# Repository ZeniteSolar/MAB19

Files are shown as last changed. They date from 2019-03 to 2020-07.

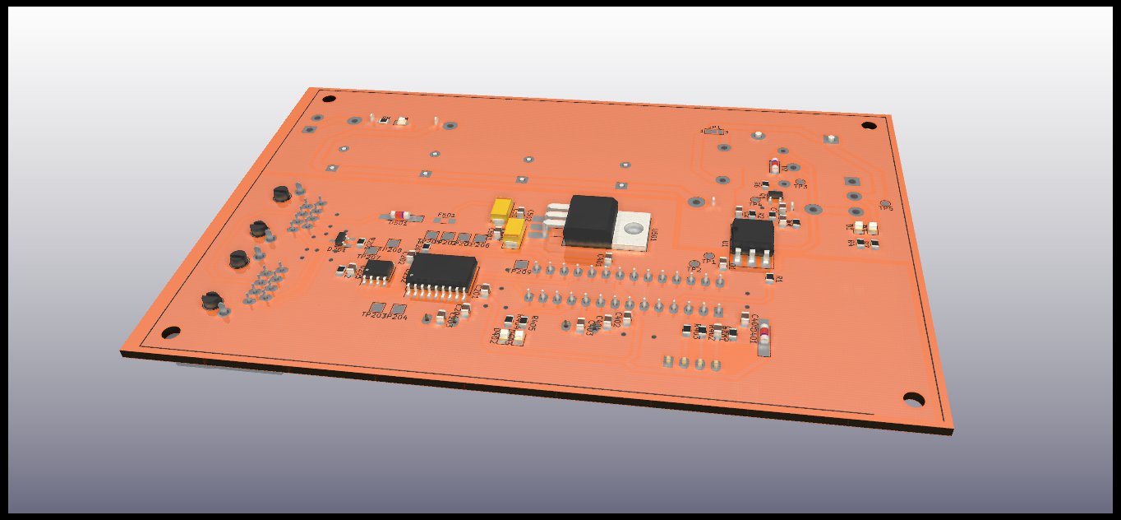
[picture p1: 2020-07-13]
hardware/IMG/3DDOWN.png

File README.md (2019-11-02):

# MAB19
Modulo de Acionamento das Bombas de porão

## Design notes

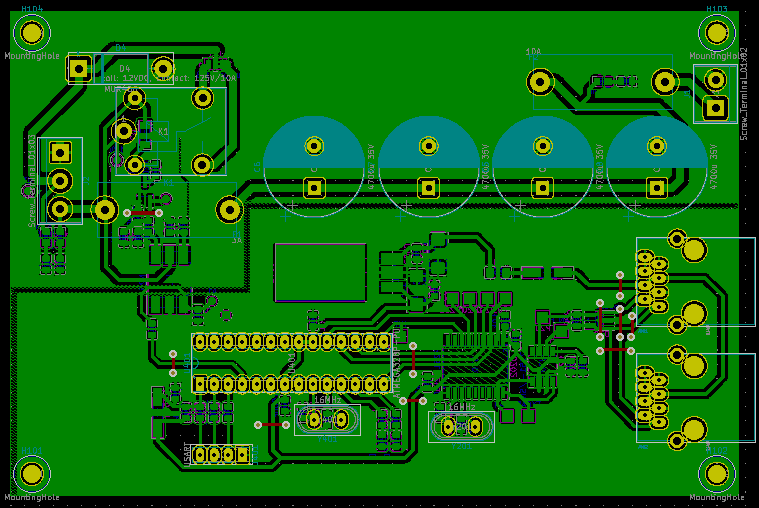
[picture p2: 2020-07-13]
hardware/IMG/layout.png

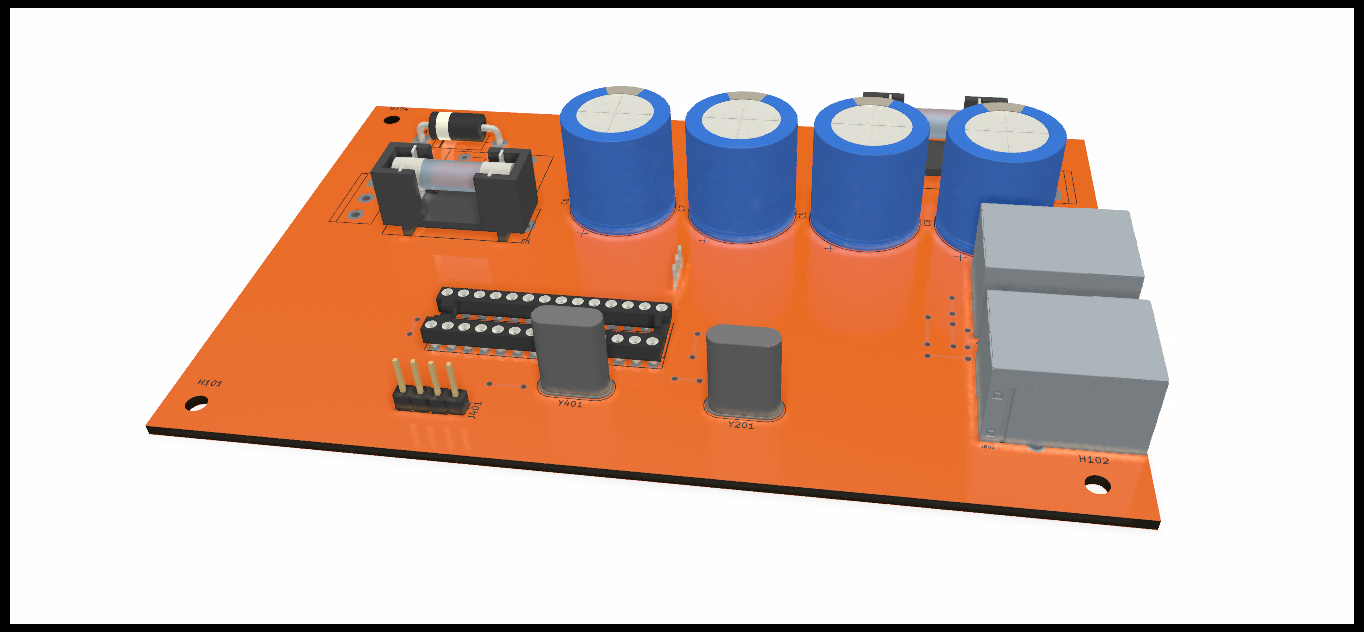
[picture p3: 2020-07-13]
hardware/IMG/3DUP.png

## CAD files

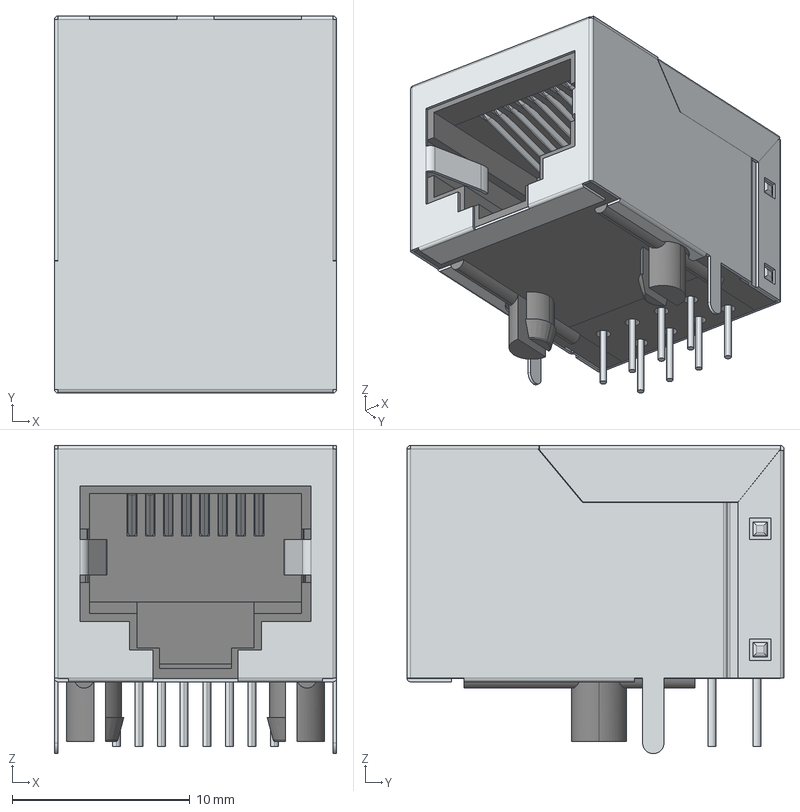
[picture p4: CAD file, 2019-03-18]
hardware/rj45.step
15.9 x 21.2 x 17.3 mm

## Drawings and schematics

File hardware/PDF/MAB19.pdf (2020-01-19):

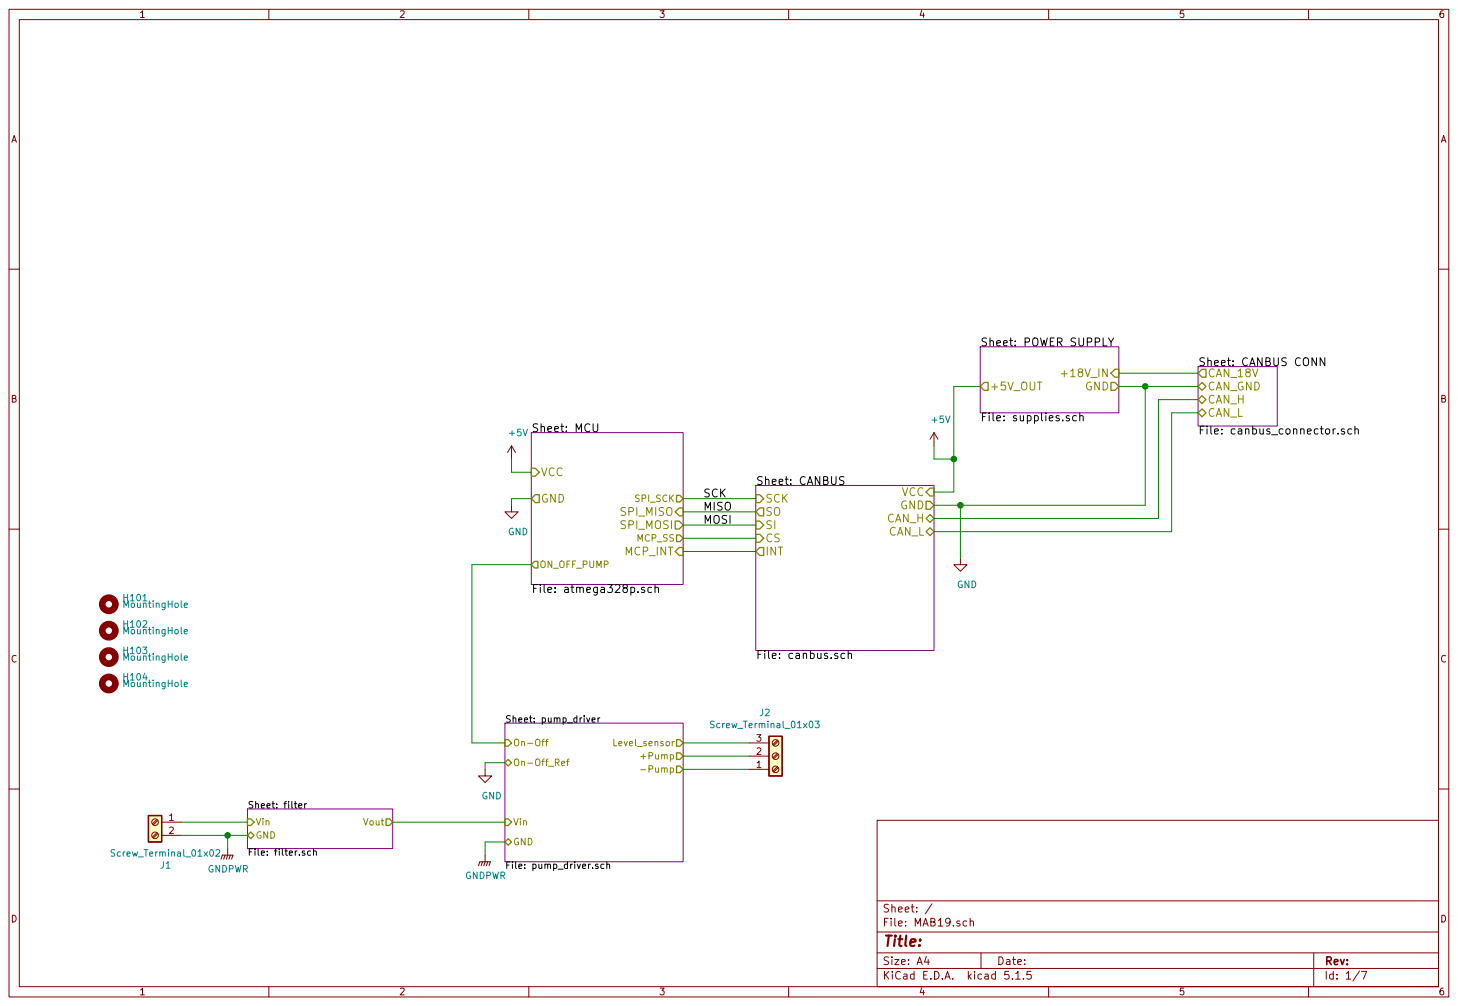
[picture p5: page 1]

Id: 1/7 Title: File: MAB19.sch Sheet: / Sheet: MCU
+5V GND GND

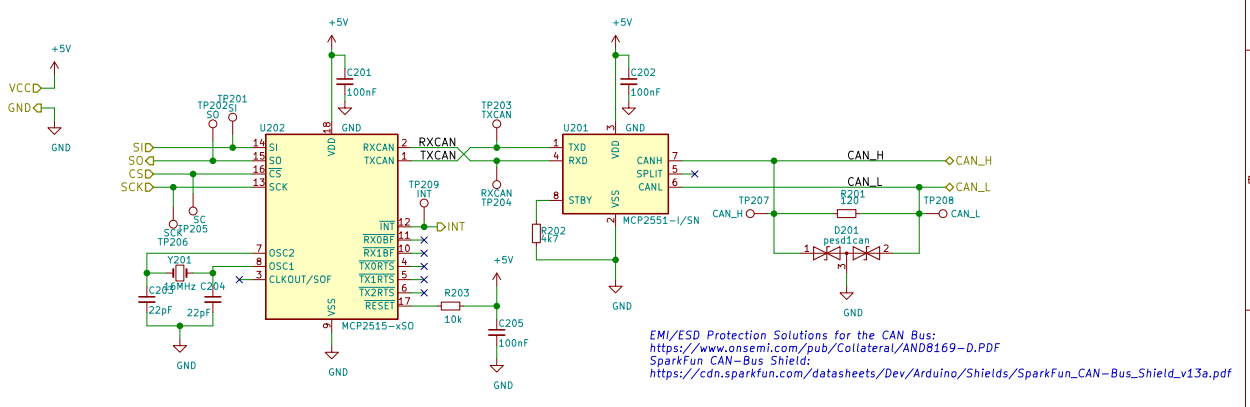
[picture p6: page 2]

3 RXD 4 SPLIT 5 CANL 6 CANH 7 STBY 8 U201 MCP2551-I/SN

EMI/ESD Protection Solutions for the CAN Bus:
https://www.onsemi.com/pub/Collateral/AND8169-D.PDF
SparkFun CAN-Bus Shield:
https://cdn.sparkfun.com/datasheets/Dev/Arduino/Shields/SparkFun_CAN-Bus_Shield_v13a.pdf

Id: 2/7 Title: File: canbus.sch Sheet: /CANBUS/

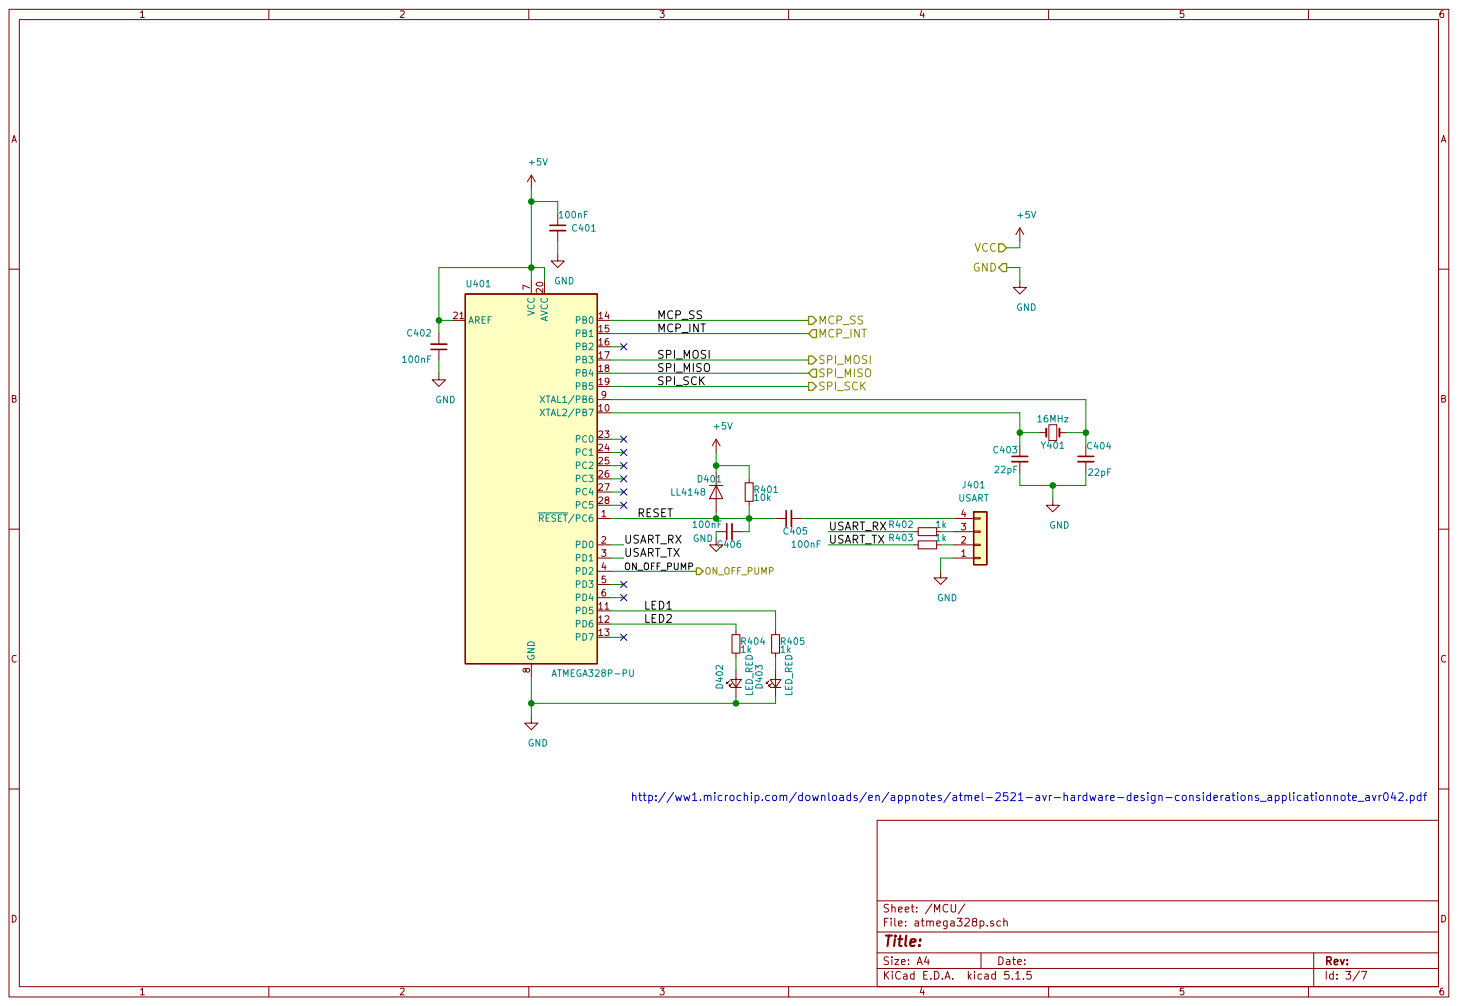
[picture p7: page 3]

http://ww1.microchip.com/downloads/en/appnotes/atmel-2521-avr-hardware-design-considerations_applicationnote_avr042.pdf

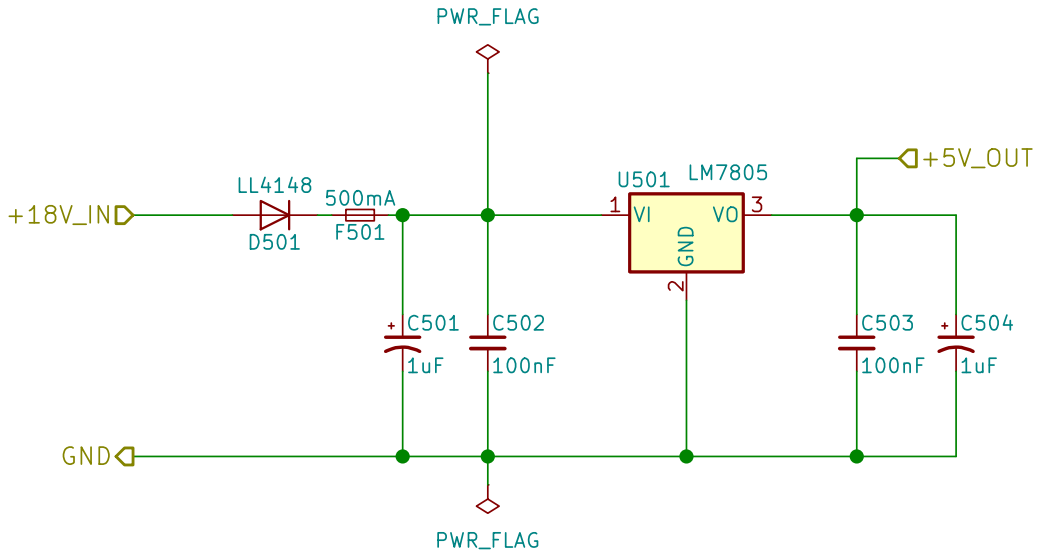
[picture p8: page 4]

File: supplies.sch Sheet: /POWER SUPPLY/
Id: 4/7 Title:

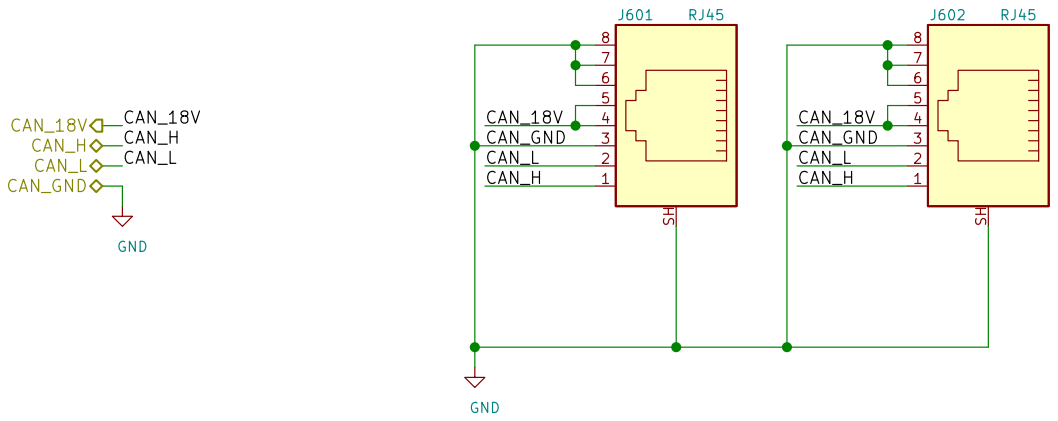
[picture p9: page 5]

File: canbus_connector.sch Sheet: /CANBUS CONN/ GND

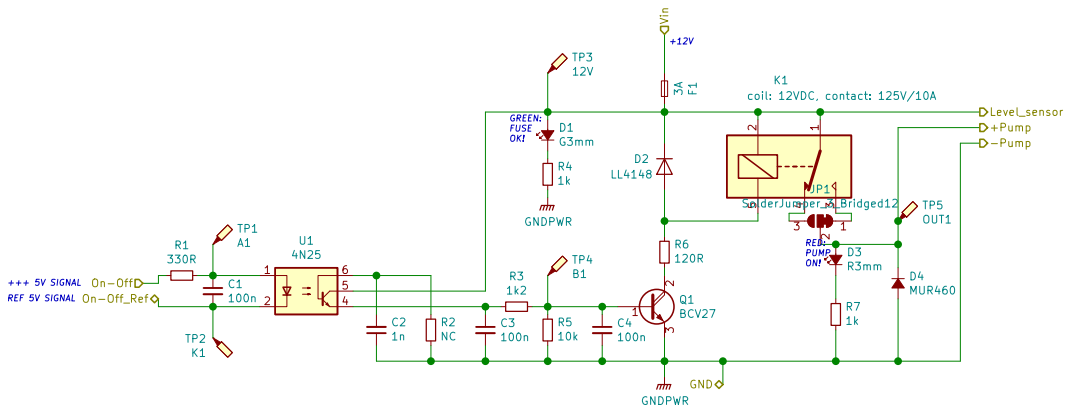
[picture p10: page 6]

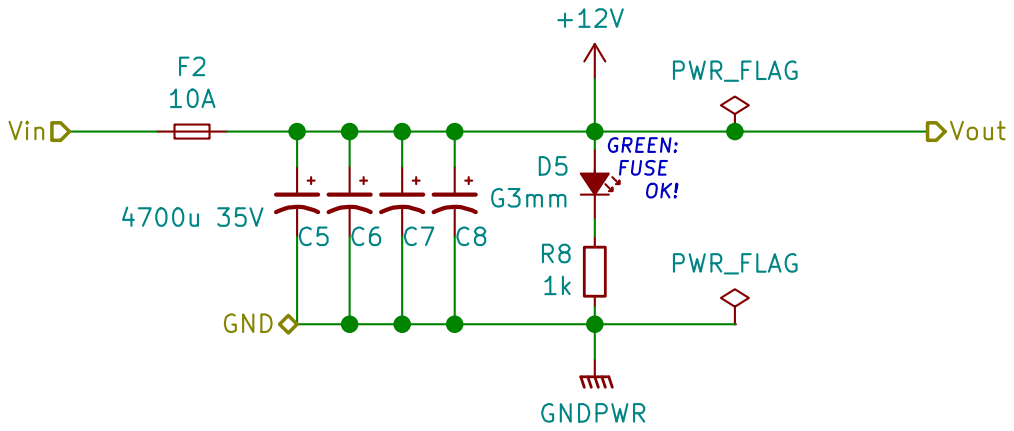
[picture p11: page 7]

Id: 7/7 Title: File: filter.sch Sheet: /filter/

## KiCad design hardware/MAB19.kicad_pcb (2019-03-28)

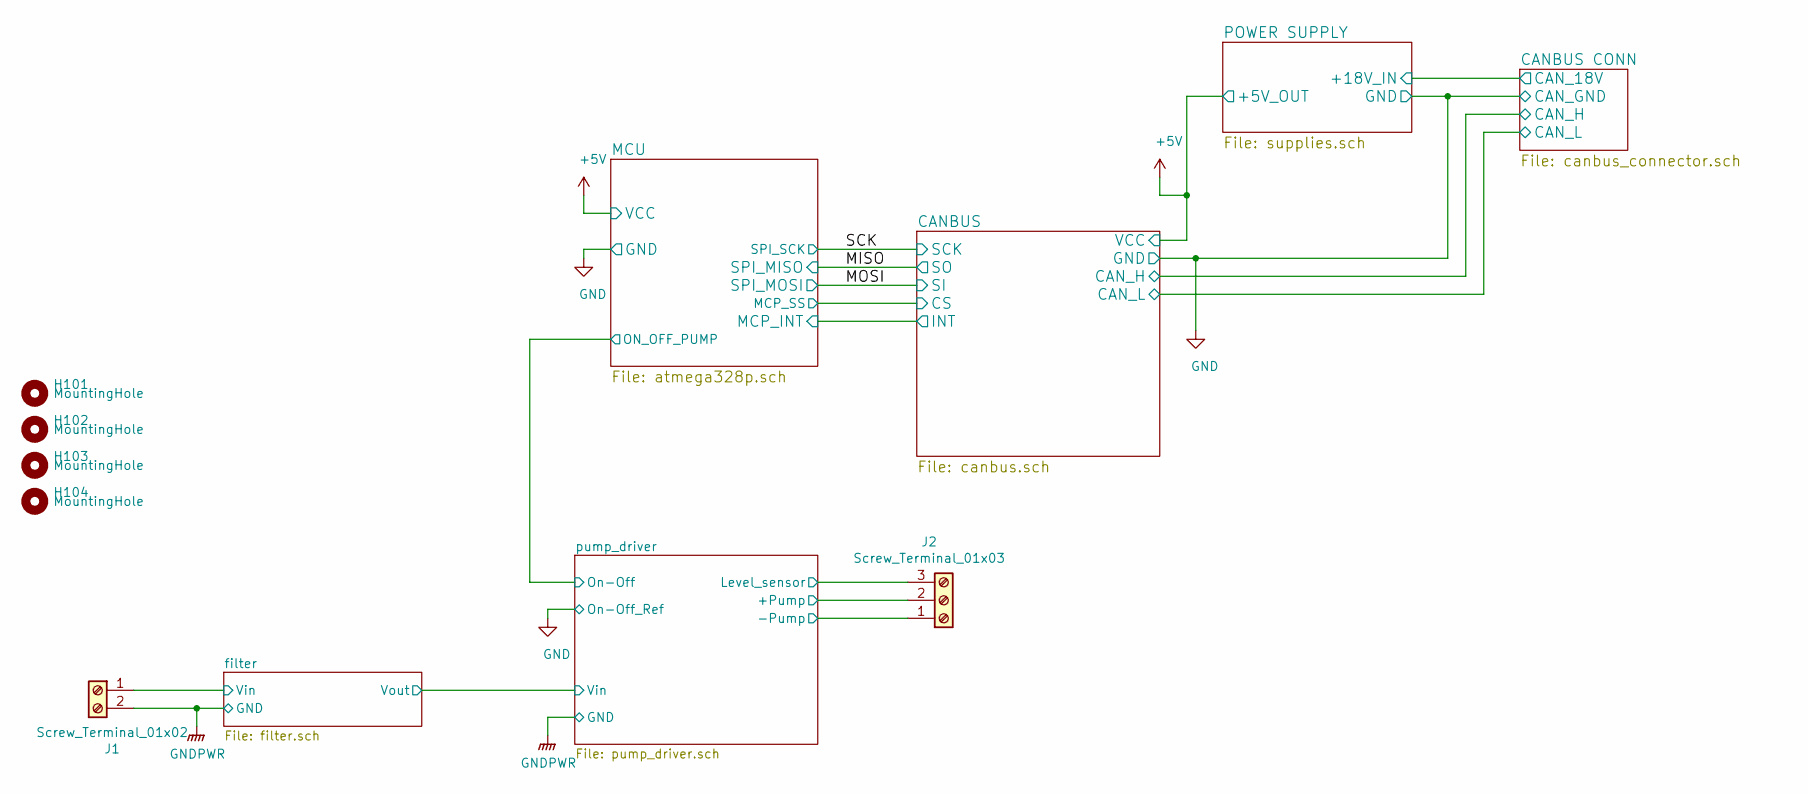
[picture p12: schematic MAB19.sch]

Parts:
H101, H102, H103, H104: MountingHole; MountingHole_3.2mm_M3
J1: Screw_Terminal_01x02; TerminalBlock_bornier-2_P5.08mm
J2: Screw_Terminal_01x03; TerminalBlock_bornier-3_P5.08mm

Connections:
/filter/Vin: J1.1; also elsewhere on the board
/pump_driver/+Pump: J2.2; also elsewhere on the board
GNDPWR: J1.2, J2.1; also elsewhere on the board

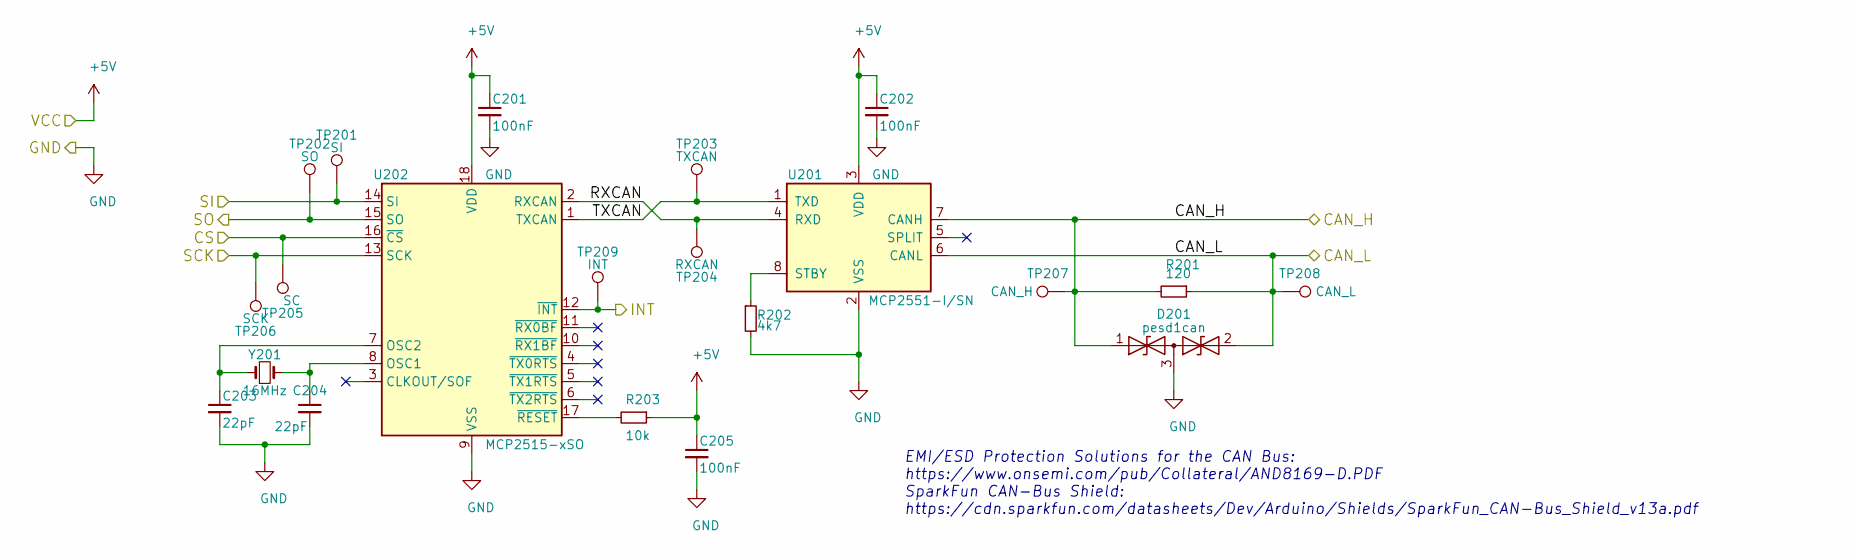
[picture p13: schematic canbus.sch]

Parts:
C201, C202, C205: 100nF; C_0805_2012Metric_Pad1.15x1.40mm_HandSolder
C203, C204: 22pF; C_0805_2012Metric_Pad1.15x1.40mm_HandSolder
D201: pesd1can; SOT-23_Handsoldering
R201: 120; R_0805_2012Metric_Pad1.15x1.40mm_HandSolder
R202: 4k7; R_0805_2012Metric_Pad1.15x1.40mm_HandSolder
R203: 10k; R_0805_2012Metric_Pad1.15x1.40mm_HandSolder
TP201: SI; TestPoint_Pad_2.0x2.0mm
TP202: SO; TestPoint_Pad_2.0x2.0mm
TP203: TXCAN; TestPoint_Pad_2.0x2.0mm
TP204: RXCAN; TestPoint_Pad_2.0x2.0mm
TP205: SC; TestPoint_Pad_2.0x2.0mm
TP206: SCK; TestPoint_Pad_2.0x2.0mm
TP207: CAN_H; TestPoint_Pad_2.0x2.0mm
TP208: CAN_L; TestPoint_Pad_2.0x2.0mm
TP209: INT; TestPoint_Pad_2.0x2.0mm
U201: MCP2551-I/SN; SOIC-8_3.9x4.9mm_P1.27mm
U202: MCP2515-xSO; SOIC-18W_7.5x11.6mm_P1.27mm
Y201: 16MHz; Crystal_HC49-U_Vertical

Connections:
+5V: C201.1, C202.1, C205.1, R203.1, U201.3 (VDD), U202.18 (VDD); also elsewhere on the board
/CANBUS CONN/CAN_H: D201.1 (A1), R201.2, TP207.1, U201.7 (CANH); also elsewhere on the board
/CANBUS CONN/CAN_L: D201.2 (A2), R201.1, TP208.1, U201.6 (CANL); also elsewhere on the board
/CANBUS/CS: TP205.1, U202.16 (~CS); also elsewhere on the board
/CANBUS/INT: TP209.1, U202.12 (~INT); also elsewhere on the board
/CANBUS/RXCAN: TP204.1, U201.4 (RXD), U202.2 (RXCAN)
/CANBUS/TXCAN: TP203.1, U201.1 (TXD), U202.1 (TXCAN)
/MISO: TP202.1, U202.15 (SO); also elsewhere on the board
/MOSI: TP201.1, U202.14 (SI); also elsewhere on the board
/SCK: TP206.1, U202.13 (SCK); also elsewhere on the board
GND: C201.2, C202.2, C203.2, C204.2, C205.2, D201.3 (common), R202.2, U201.2 (VSS), U202.9 (VSS); also elsewhere on the board
unnamed: C203.1, U202.7 (OSC2), Y201.1
unnamed: C204.1, U202.8 (OSC1), Y201.2
unnamed: R202.1, U201.8 (STBY)
unnamed: R203.2, U202.17 (~RESET)

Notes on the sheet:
EMI/ESD Protection Solutions for the CAN Bus: https://www.onsemi.com/pub/Collateral/AND8169-D.PDF SparkFun CAN-Bus Shield: https://cdn.sparkfun.com/datasheets/Dev/Arduino/Shields/SparkFun_CAN-Bus_Shield_v13a.pdf

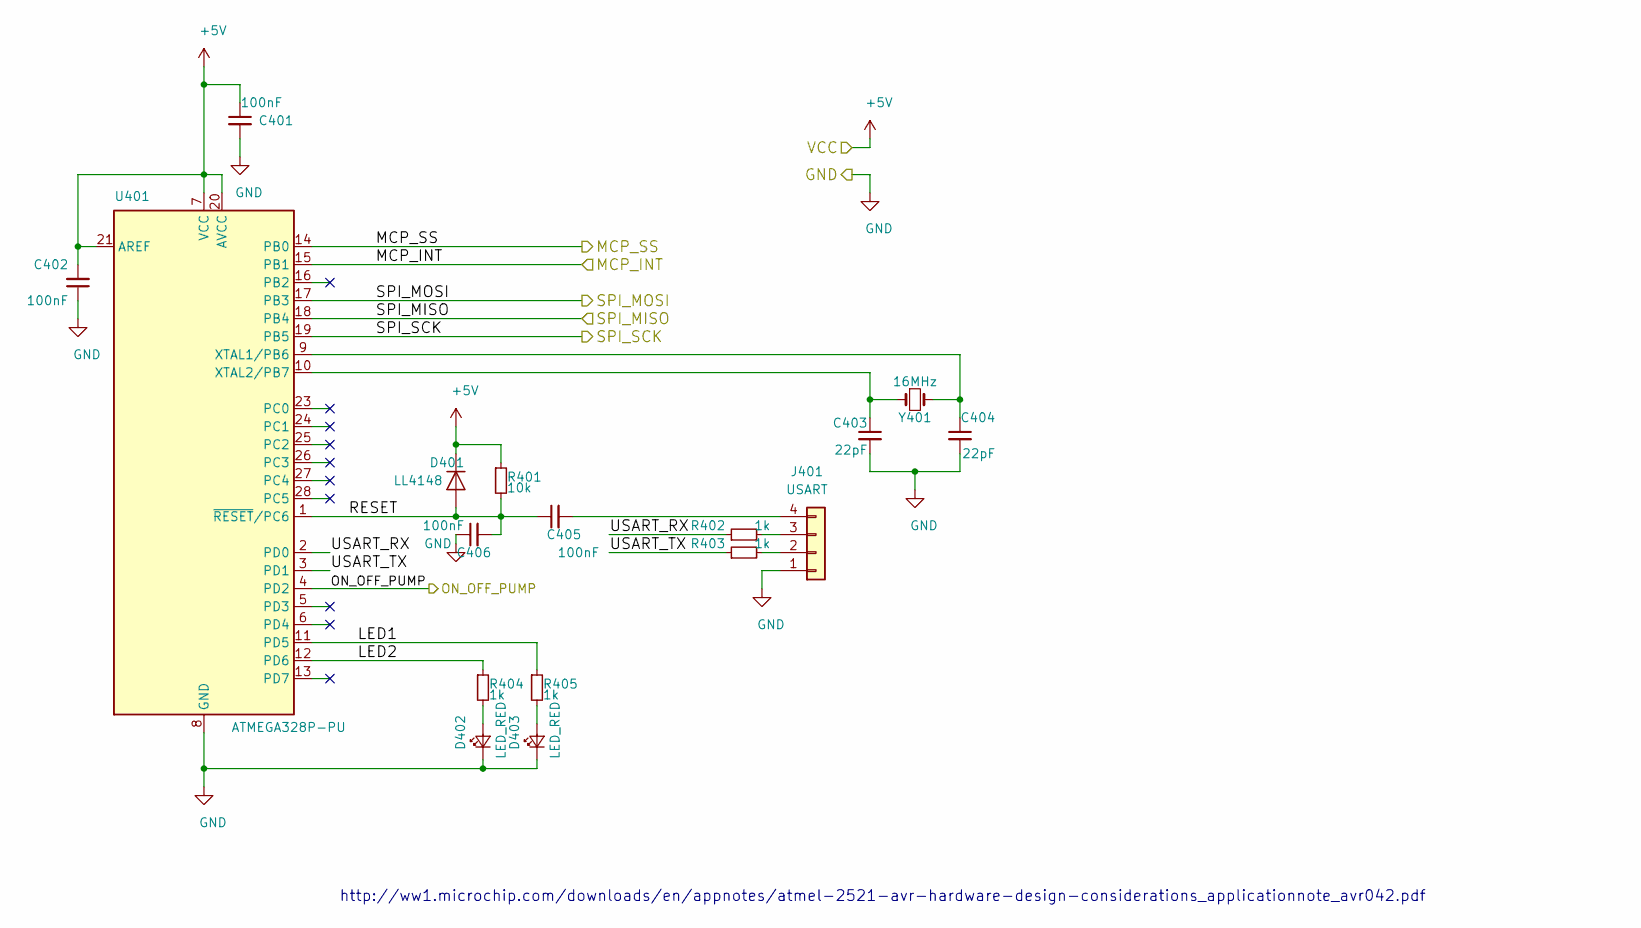
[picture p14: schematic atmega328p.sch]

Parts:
C401, C402, C405, C406: 100nF; C_0805_2012Metric_Pad1.15x1.40mm_HandSolder
C403, C404: 22pF; C_0805_2012Metric_Pad1.15x1.40mm_HandSolder
D401: LL4148; D_MiniMELF_Handsoldering
D402, D403: LED_RED; LED_0805_2012Metric_Pad1.15x1.40mm_HandSolder
J401: USART; PinHeader_1x04_P2.54mm_Vertical
R401: 10k; R_0805_2012Metric_Pad1.15x1.40mm_HandSolder
R402, R403, R404, R405: 1k; R_0805_2012Metric_Pad1.15x1.40mm_HandSolder
U401: ATMEGA328P-PU; DIP-28_W7.62mm_Socket
Y401: 16MHz; Crystal_HC49-U_Vertical

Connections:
+5V: C401.1, C402.2, D401.1 (K), R401.1, U401.7 (VCC), U401.20 (AVCC), U401.21 (AREF); also elsewhere on the board
/CANBUS/CS: U401.14 (PB0); also elsewhere on the board
/CANBUS/INT: U401.15 (PB1); also elsewhere on the board
/MCU/LED1: R405.1, U401.11 (PD5)
/MCU/LED2: R404.1, U401.12 (PD6)
/MCU/ON_OFF_PUMP: U401.4 (PD2); also elsewhere on the board
/MCU/RESET: C405.1, C406.2, D401.2 (A), R401.2, U401.1 (~RESET~/PC6)
/MCU/USART_RX: R402.1, U401.2 (PD0)
/MCU/USART_TX: R403.1, U401.3 (PD1)
/MISO: U401.18 (PB4); also elsewhere on the board
/MOSI: U401.17 (PB3); also elsewhere on the board
/SCK: U401.19 (PB5); also elsewhere on the board
GND: C401.2, C402.1, C403.2, C404.2, C406.1, D402.1 (K), D403.1 (K), J401.1, U401.8 (GND), U401.22 (GND); also elsewhere on the board
unnamed: C403.1, U401.10 (XTAL2/PB7), Y401.1
unnamed: C404.1, U401.9 (XTAL1/PB6), Y401.2
unnamed: C405.2, J401.4
unnamed: D402.2 (A), R404.2
unnamed: D403.2 (A), R405.2
unnamed: J401.2, R403.2
unnamed: J401.3, R402.2

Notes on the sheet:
http://ww1.microchip.com/downloads/en/appnotes/atmel-2521-avr-hardware-design-considerations_applicationnote_avr042.pdf

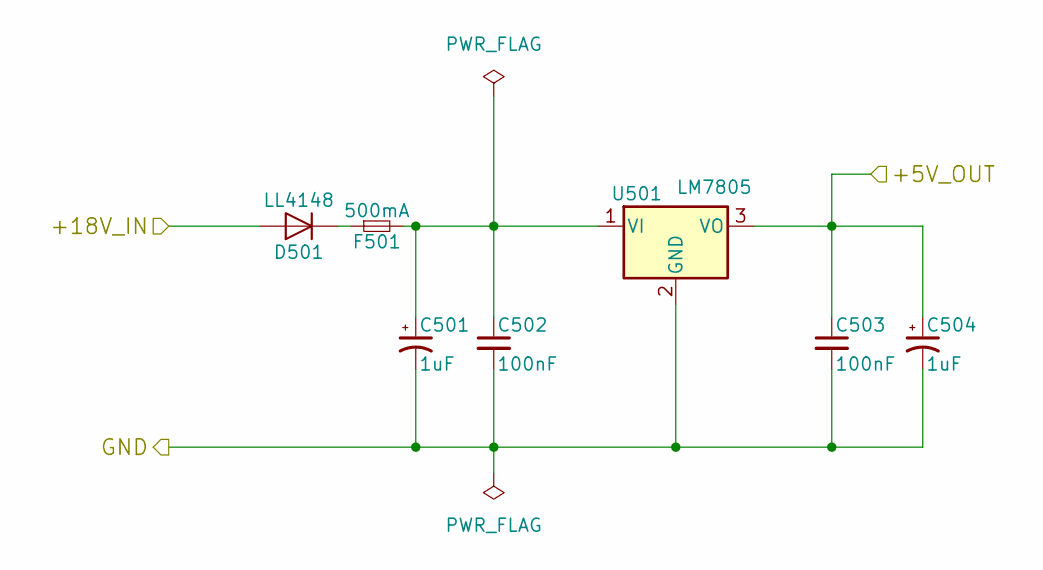
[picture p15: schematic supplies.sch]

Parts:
C501, C504: 1uF; CP_EIA-6032-20_AVX-F_Pad2.25x2.35mm_HandSolder
C502, C503: 100nF; C_0805_2012Metric_Pad1.15x1.40mm_HandSolder
D501: LL4148; D_MiniMELF_Handsoldering
F501: 500mA; Fuse_1206_3216Metric_Pad1.42x1.75mm_HandSolder
U501: LM7805; TO-220-3_Horizontal_TabDown_SMD

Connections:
+5V: C503.1, C504.1, U501.3 (VO); also elsewhere on the board
/POWER SUPPLY/+18V_IN: D501.2 (A); also elsewhere on the board
GND: C501.2, C502.2, C503.2, C504.2, U501.2 (GND); also elsewhere on the board
unnamed: C501.1, C502.1, F501.2, U501.1 (VI)
unnamed: D501.1 (K), F501.1

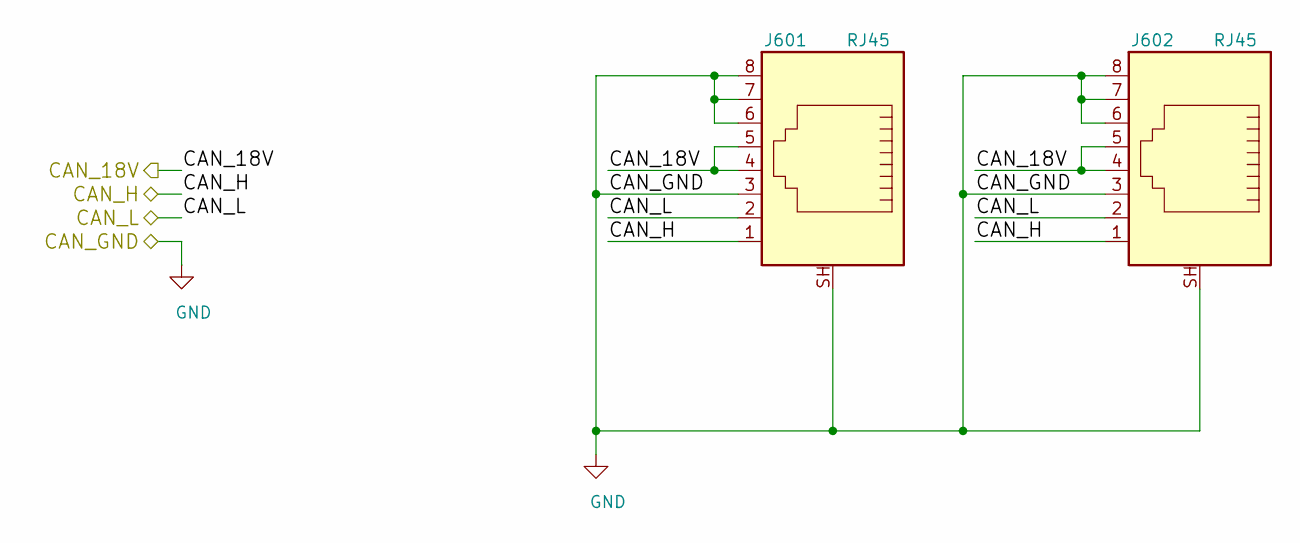
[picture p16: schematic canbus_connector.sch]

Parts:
J601, J602: RJ45; RJ45_YH59_01

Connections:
/CANBUS CONN/CAN_H: J601.1, J602.1; also elsewhere on the board
/CANBUS CONN/CAN_L: J601.2, J602.2; also elsewhere on the board
/POWER SUPPLY/+18V_IN: J601.4, J601.5, J602.4, J602.5; also elsewhere on the board
GND: J601.3, J601.6, J601.7, J601.8, J601.SH, J602.3, J602.6, J602.7, J602.8, J602.SH; also elsewhere on the board

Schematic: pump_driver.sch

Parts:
C1, C3, C4: 100n; C_0805_2012Metric_Pad1.15x1.40mm_HandSolder
C2: 1n; C_0805_2012Metric_Pad1.15x1.40mm_HandSolder
D1: G3mm; LED_0805_2012Metric_Pad1.15x1.40mm_HandSolder
D2: LL4148; D_MiniMELF
D3: R3mm; LED_0805_2012Metric_Pad1.15x1.40mm_HandSolder
D4: MUR460; D_DO-201AD_P15.24mm_Horizontal
F1: 3A; Fuse_Holder_5x20
JP1: SolderJumper_3_Bridged12; SolderJumper-3_P1.3mm_Bridged2Bar12_Pad1.0x1.5mm_NumberLabe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
K1: coil: 12VDC, contact: 125V/10A; Relay_SPDT_SANYOU_SRD_Series_Form_C
Q1: BCV27; TSOT-23_HandSoldering
R1: 330R; R_0805_2012Metric_Pad1.15x1.40mm_HandSolder
R2: NC; R_0805_2012Metric_Pad1.15x1.40mm_HandSolder
R3: 1k2; R_0805_2012Metric_Pad1.15x1.40mm_HandSolder
R4, R7: 1k; R_0805_2012Metric_Pad1.15x1.40mm_HandSolder
R5: 10k; R_0805_2012Metric_Pad1.15x1.40mm_HandSolder
R6: 120R; R_0805_2012Metric_Pad1.15x1.40mm_HandSolder
TP1: A1; TestPoint_Pad_D1.5mm
TP2: K1; TestPoint_Pad_D1.5mm
TP3: 12V; TestPoint_Pad_D1.5mm
TP4: B1; TestPoint_Pad_D1.5mm
TP5: OUT1; TestPoint_Pad_D1.5mm
U1: 4N25; DIP-6_W8.89mm_SMDSocket_LongPads

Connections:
+12V: F1.1; also elsewhere on the board
/MCU/ON_OFF_PUMP: R1.2; also elsewhere on the board
/pump_driver/+Pump: D3.2 (A), D4.1 (K), JP1.2 (C), TP5.1; also elsewhere on the board
GND: C1.2, TP2.1, U1.2; also elsewhere on the board
GNDPWR: C2.1, C3.2, C4.2, D4.2 (A), Q1.2, R2.1, R4.1, R5.1, R7.1; also elsewhere on the board
unnamed: C1.1, R1.1, TP1.1, U1.1
unnamed: C2.2, R2.2, U1.6
unnamed: C3.1, R3.2, U1.4
unnamed: C4.1, Q1.1, R3.1, R5.2, TP4.1
unnamed: D1.1 (K), R4.2
unnamed: D3.1 (K), R7.2
unnamed: JP1.1 (A), K1.3
unnamed: JP1.3 (B), K1.4
unnamed: Q1.3, R6.1

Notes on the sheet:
RED: PUMP ON!
GREEN: FUSE OK!
+++ 5V SIGNAL
REF 5V SIGNAL
+12V

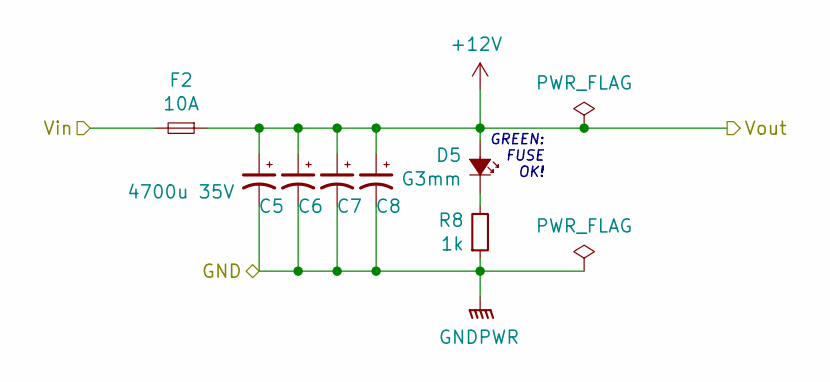
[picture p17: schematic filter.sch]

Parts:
C20, C21, C22, C23: 4700u 35V; CP_Radial_D18.0mm_P7.50mm
D10: G3mm; LED_0805_2012Metric_Pad1.15x1.40mm_HandSolder
F3: 10A; Fuse_Holder_5x20
R16: 1k; R_0805_2012Metric_Pad1.15x1.40mm_HandSolder

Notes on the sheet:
GREEN: FUSE OK!

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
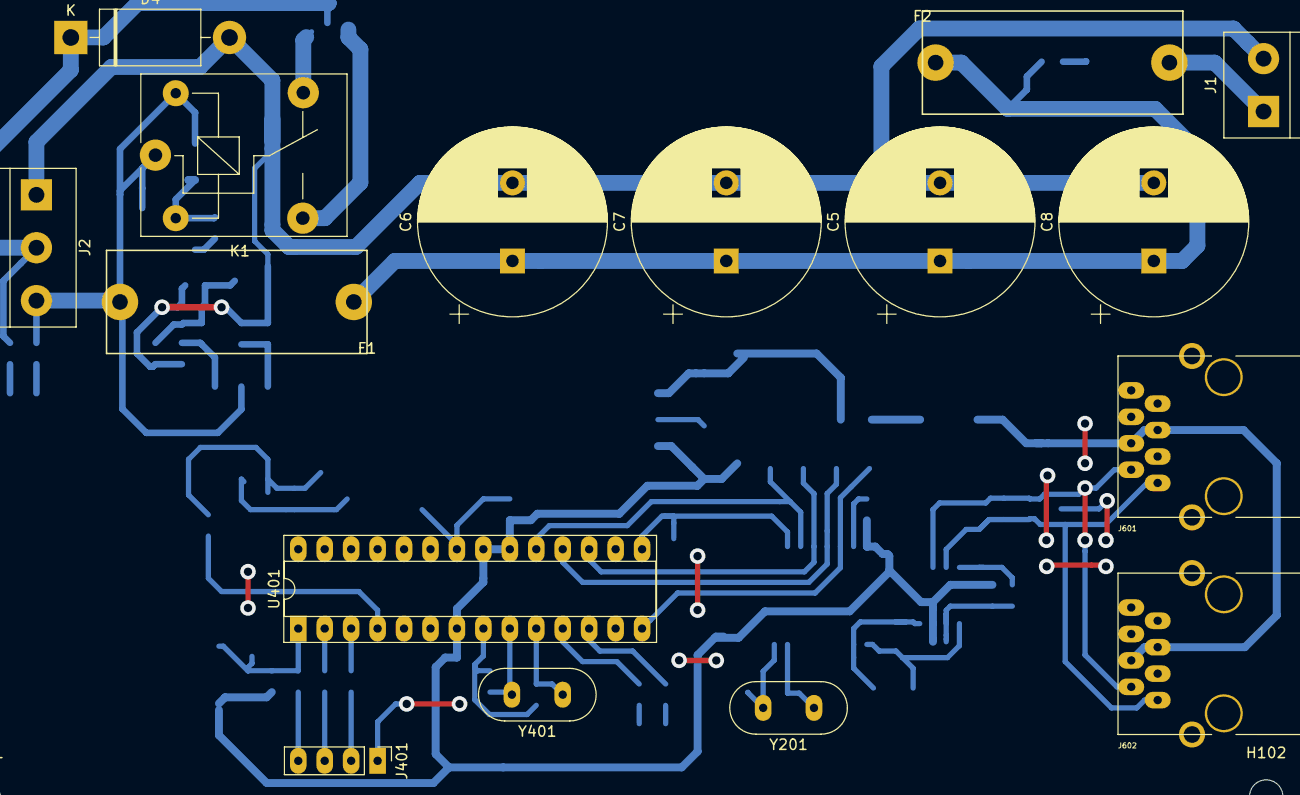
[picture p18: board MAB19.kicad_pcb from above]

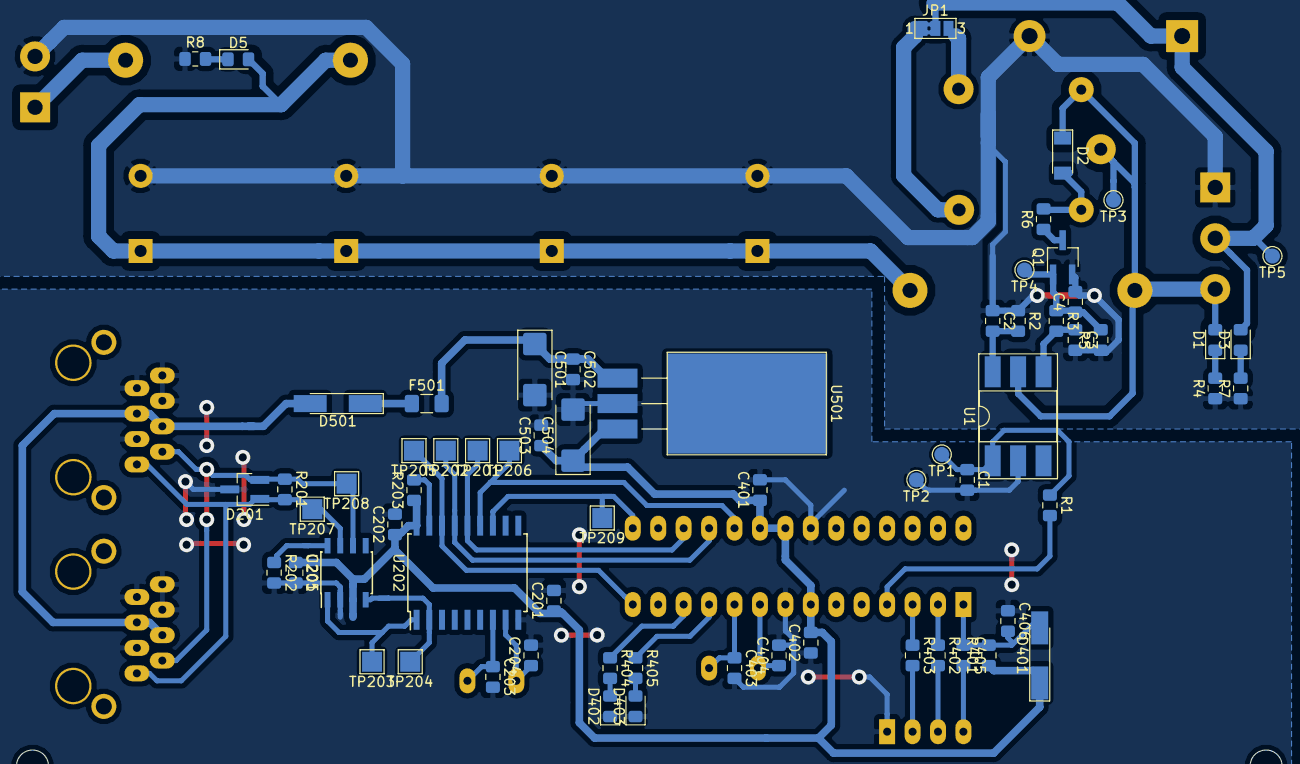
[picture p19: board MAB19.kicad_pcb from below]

Board: 2 copper layers, 85 parts (65 on the bottom side), 47 nets.

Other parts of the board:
C5, C6, C7, C8: 4700u 35V; CP_Radial_D18.0mm_P7.50mm
D5: G3mm; LED_0805_2012Metric_Pad1.15x1.40mm_HandSolder
F2: 10A; Fuse_Holder_5x20
R8: 1k; R_0805_2012Metric_Pad1.15x1.40mm_HandSolder

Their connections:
+12V: C5.1, C6.1, C7.1, C8.1, D5.2, F2.1; also elsewhere on the board
/filter/Vin: F2.2; also elsewhere on the board
GNDPWR: C5.2, C6.2, C7.2, C8.2, R8.1; also elsewhere on the board
unnamed: D5.1, R8.2

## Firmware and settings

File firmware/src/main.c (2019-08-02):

// coding: utf-8

#include "main.h"

void init(void)
{
    #ifdef USART_ON
        usart_init(MYUBRR,1,1);                         // inicializa a usart
        VERBOSE_MSG_INIT(usart_send_string("\n\n\nUSART... OK!\n"));
    #endif

    #ifdef WATCHDOG_ON
        VERBOSE_MSG_INIT(usart_send_string("WATCHDOG..."));
        wdt_init();
        VERBOSE_MSG_INIT(usart_send_string(" OK!\n"));
        wdt_reset();
    #else
        VERBOSE_MSG_INIT(usart_send_string("WATCHDOG... OFF!\n"));
    #endif

    #ifdef WATCHDOG_ON
        wdt_reset();
    #endif

    #ifdef SPI_ON
        set_bit(DDRB, PB2);     //output to be the spi master
    #endif

    #ifdef CAN_ON
        VERBOSE_MSG_INIT(usart_send_string("CAN (500kbps)..."));
        can_init(BITRATE_500_KBPS);
        //can_set_mode(LOOPBACK_MODE);
        VERBOSE_MSG_INIT(usart_send_string(" OK!\n"));
        VERBOSE_MSG_INIT(usart_send_string("CAN filters..."));
        can_static_filter(can_filter);
        VERBOSE_MSG_INIT(usart_send_string(" OK!\n"));
    #else
        VERBOSE_MSG_INIT(usart_send_string("CAN... OFF!\n"));
    #endif

    #ifdef WATCHDOG_ON
        wdt_reset();
    #endif

    #ifdef ADC_ON
        VERBOSE_MSG_INIT(usart_send_string("ADC..."));
        adc_init();
        VERBOSE_MSG_INIT(usart_send_string(" OK!\n"));
    #else
        VERBOSE_MSG_INIT(usart_send_string("ADC... OFF!\n"));
    #endif

    #ifdef WATCHDOG_ON
        wdt_reset();
    #endif

    #ifdef SLEEP_ON
        VERBOSE_MSG_INIT(usart_send_string("SLEEP..."));
        sleep_init();
        VERBOSE_MSG_INIT(usart_send_string(" OK!\n"));
    #else
        VERBOSE_MSG_INIT(usart_send_string("SLEEP... OFF!\n"));
    #endif

    #ifdef WATCHDOG_ON
        wdt_reset();
    #endif

 	#ifdef MACHINE_ON
        VERBOSE_MSG_INIT(usart_send_string("MACHINE..."));
		    machine_init();
        VERBOSE_MSG_INIT(usart_send_string(" OK!\n"));
    #else
        VERBOSE_MSG_INIT(usart_send_string("MACHINE... OFF!\n"));
	#endif

    #ifdef WATCHDOG_ON
        wdt_reset();
    #endif

    #ifdef LED_ON
        set_bit(LED_DDR, LED1);                      // LED como saída
        set_bit(LED_DDR, LED2);                      // LED como saída
        VERBOSE_MSG_INIT(usart_send_string("LED... OK!\n"));
    #else
        VERBOSE_MSG_INIT(usart_send_string("LED... OFF!\n"));
    #endif

        set_bit(PUMP_DDR, PUMP);
        VERBOSE_MSG_INIT(usart_send_string("Pump... OK!\n"));

    #ifdef WATCHDOG_ON
        wdt_reset();
    #endif

    #ifdef MACHINE_ON
        print_configurations();
    #endif // MACHINE_ON

    sei();
}

int main(void)
{
    init();

	for(;;){
	#ifdef WATCHDOG_ON
        wdt_reset();
	#endif

  #ifdef MACHINE_ON
        machine_run();
  #endif

	#ifdef SLEEP_ON
        sleep_mode();
	#endif
	}
}


/**
 * @brief se em debug, fica chaveando os pinos de debugs até o reset do watchdog
 */
ISR(BADISR_vect)
{
    for(;;){
        VERBOSE_MSG_ERROR(usart_send_string("\nFATAL ERROR: BAD ISR."));
        #ifdef WATCHDOG_ON
            VERBOSE_MSG_ERROR(usart_send_string("WAITING FOR WATCHDOG TO RESET...\n"));
        #endif
        #ifdef DEBUG_ON
            DEBUG0;
            DEBUG1;
            _delay_ms(100);
        #endif
    }
}

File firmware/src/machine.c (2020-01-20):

#include "machine.h"

/**
 * @brief
 */
void machine_init(void)
{
	//clr_bit(PRR0, PRTIM2);                          // Activates clock

    // MODE 2 -> CTC with TOP on OCR1
    TCCR2A  =    (1 << WGM21) | (0 << WGM20)        // mode 2
              | (0 << COM2B1) | (0 << COM2B0)       // do nothing
              | (0 << COM2A1) | (0 << COM2A0);      // do nothing

    TCCR2B =
#if MACHINE_TIMER_PRESCALER ==     1
                (0 << CS22) | (0 << CS21) | (1 << CS20) // Prescaler N=1
#elif MACHINE_TIMER_PRESCALER ==   8
                (0 << CS22) | (1 << CS21) | (0 << CS20) // Prescaler N=8
#elif MACHINE_TIMER_PRESCALER ==   32
                (0 << CS22) | (1 << CS21) | (1 << CS20) // Prescaler N=32
#elif MACHINE_TIMER_PRESCALER ==   64
                (1 << CS22) | (0 << CS21) | (0 << CS20) // Prescaler N=64
#elif MACHINE_TIMER_PRESCALER ==   128
                (1 << CS22) | (0 << CS21) | (1 << CS20) // Prescaler N=128
#elif MACHINE_TIMER_PRESCALER ==   256
                (1 << CS22) | (1 << CS21) | (0 << CS20) // Prescaler N=256
#elif MACHINE_TIMER_PRESCALER ==   1024
                (1 << CS22) | (1 << CS21) | (1 << CS20) // Prescaler N=1024
#else
                0
#endif
                | (0 << WGM22);      // mode 2

    OCR2A = MACHINE_TIMER_TOP;                       // OCR2A = TOP = fcpu/(N*2*f) -1

    TIMSK2 |=   (1 << OCIE2A);                      // Activates interruption

    set_machine_initial_state();
    set_state_initializing();
}

/**
 * @brief set machine initial state
 */
inline void set_machine_initial_state(void)
{
    error_flags.all = 0;
    machine_clk = machine_clk_divider = led_clk_div = 0;
}

/**
 * @brief set error state
 */
inline void set_state_error(void)
{
    VERBOSE_MSG_MACHINE(usart_send_string("\n>>>STATE ERROR\n"));
    state_machine = STATE_ERROR;
}

/**
* @brief set initializing state
*/
inline void set_state_initializing(void)
{
    VERBOSE_MSG_MACHINE(usart_send_string("\n>>>INITIALIZING STATE\n"));
    state_machine = STATE_INITIALIZING;
}

/**
* @brief set idle state
*/
inline void set_state_idle(void)
{
    VERBOSE_MSG_MACHINE(usart_send_string("\n>>>IDLE STATE\n"));
    state_machine = STATE_IDLE;
}

/**
* @brief set running state
*/
inline void set_state_running(void)
{
    VERBOSE_MSG_MACHINE(usart_send_string("\n>>>RUNNING STATE\n"));
    state_machine = STATE_RUNNING;
}

/**
 * @brief set reset state
 */
inline void set_state_reset(void)
{
    VERBOSE_MSG_MACHINE(usart_send_string("\n>>>RESET STATE\n"));
    state_machine = STATE_RESET;
}

/**
 * @breif prints the configurations and definitions
 */
inline void print_configurations(void)
{
    VERBOSE_MSG_MACHINE(usart_send_string("CONFIGURATIONS:\n"));

#ifdef ADC_ON
    VERBOSE_MSG_MACHINE(usart_send_string("\nadc_f: "));
    VERBOSE_MSG_MACHINE(usart_send_uint16( ADC_FREQUENCY ));
    VERBOSE_MSG_MACHINE(usart_send_char(','));
    VERBOSE_MSG_MACHINE(usart_send_uint16( ADC_AVG_SIZE_10 ));
#endif // ADC_ON

    VERBOSE_MSG_MACHINE(usart_send_string("\nmachine_f: "));
    VERBOSE_MSG_MACHINE(usart_send_uint16( MACHINE_FREQUENCY ));
    VERBOSE_MSG_MACHINE(usart_send_char('\n'));
}

/**
* @brief prints the system flags
*/
inline void print_system_flags(void)
{
    //VERBOSE_MSG_MACHINE(usart_send_string(" EN "));
    //VERBOSE_MSG_MACHINE(usart_send_char(48+system_flags.enable));
}

/**
* @brief prints the error flags
*/
inline void print_error_flags(void)
{
    //VERBOSE_MSG_MACHINE(usart_send_string(" errFl: "));
    //VERBOSE_MSG_MACHINE(usart_send_char(48+error_flags.no_canbus));
}

/**
 * @brief Checks if the system is OK to run
 */
inline void task_initializing(void)
{
#ifdef LED_ON
    set_led(LED1);
#endif

    set_machine_initial_state();
    clr_pump();
    VERBOSE_MSG_INIT(usart_send_string("System initialized without errors.\n"));
    set_state_idle();
}

/**
 * @brief waits for commands while checking the system
 */
inline void task_idle(void)
{
#ifdef LED_ON
    if(led_clk_div++ >= 60){
        cpl_led(LED1);
        led_clk_div = 0;
    }
#endif

    set_state_running();
}


/**
 * @brief apply the control action to pump.
 */
inline void task_running(void)
{
  #ifdef LED_ON
      if(led_clk_div++ >= 30){
          cpl_led(LED1);
          led_clk_div = 0;
      }
  #endif // LED_ON

  if(system_flags.pump_on)
  {
    set_pump();
    set_led(LED2);
  }
  else
  {
    clr_pump();
    clr_led(LED2);
  }
}
/**
 * @brief error task checks the system and tries to medicine it.
 */
inline void task_error(void)
{
#ifdef LED_ON
    if(led_clk_div++ >= 5){
        cpl_led(LED2);
        cpl_led(LED1);
        led_clk_div = 0;
    }
#endif

    total_errors++;         // incrementa a contagem de erros
    VERBOSE_MSG_ERROR(usart_send_string("The error code is: "));
    VERBOSE_MSG_ERROR(usart_send_uint16(error_flags.all));
    VERBOSE_MSG_ERROR(usart_send_char('\n'));

    if(error_flags.no_canbus)
        VERBOSE_MSG_ERROR(usart_send_string("\t - No canbus communication with MIC19!\n"));
    if(!error_flags.all)
        VERBOSE_MSG_ERROR(usart_send_string("\t - Oh no, it was some unknown error.\n"));

    VERBOSE_MSG_ERROR(usart_send_string("The error level is: "));
    VERBOSE_MSG_ERROR(usart_send_uint16(total_errors));
    VERBOSE_MSG_ERROR(usart_send_char('\n'));

    if(total_errors < 2){
        VERBOSE_MSG_ERROR(usart_send_string("I will reset the machine state.\n"));
    }
    if(total_errors >= 20){
        VERBOSE_MSG_ERROR(usart_send_string("The watchdog will reset the whole system.\n"));
        set_state_reset();
    }

#ifdef LED_ON
    cpl_led(LED2);
#endif
    set_state_initializing();

}


/**
 * @brief reset error task just freezes the processor and waits for watchdog
 */
inline void task_reset(void)
{
#ifndef WATCHDOG_ON
    //wdt_init();
#endif

    cli();  // disable interrupts

    VERBOSE_MSG_ERROR(usart_send_string("WAITING FOR A RESET!\n"));
    for(;;)
    {
      cpl_led(LED2);
      cpl_led(LED1);
      _delay_ms(100);
    }
}

void print_infos(void)
{
    static uint8_t i = 0;

    switch(i++){
        case 0:
            //print_system_flags();
            break;
        case 1:
            //print_error_flags();
            break;
        case 2:
            //print_control_others();
        default:
            //VERBOSE_MSG_MACHINE(usart_send_char('\n'));
            i = 0;
            break;
    }
}
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

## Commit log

2019-03-18 Importados os esquematicos do MAB18 para o projeto do MCS19 para usar o can e uC
    [MAB19.kicad_pcb, MAB19.sch, analog.sch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]
2019-03-18 Adicionado safe zone para separar os GNDs
    [MAB19.kicad_pcb]
2019-03-18 Pequena alteeração
    [MAB19.kicad_pcb]
2019-03-19 First version PCB
    [MAB19.kicad_pcb, MAB19.sch, atmega328p.sch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]
2019-03-19 Foram reorganizadas algumas zonas para diminuir as dimensoes
    [MAB19.kicad_pcb]
2019-03-19 Foram reposicionados os conectores Pois onde eles estavam não permitiam que ouvese uma placa igual do lado
    [MAB19.kicad_pcb, _saved_canbus.sch]
2019-03-28 Solucionado erro na disposição dos pinos do BCV27
    [MAB19.kicad_pcb]
2019-04-29 Organização dos arquivos
    [_saved_canbus.sch]
2020-01-19 reorganized, 3d exported
    [MAB19.kicad_pcb, MAB19.sch, analog.sch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]
2020-07-19 clone of MAB19
    [MAB19_PANEL.kicad_pcb]
2020-07-19 Revert "gitignore"
    This reverts commit e70b843413eae7443d92e3db1b3329385fe013be.
    [MAB19.kicad_pcb, MAB19.sch]
2020-07-19 Revert "clone of MAB19"
    This reverts commit 65590e10a33a90435167e6ac9149648b248fbad7.
    [MAB19_PANEL.kicad_pcb]
